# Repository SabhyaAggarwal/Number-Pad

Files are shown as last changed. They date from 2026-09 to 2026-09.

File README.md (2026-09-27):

# Number Pad
This is a keyboard made by me that acts as a number pad for many keyboards today that don't include it, and it's designed for use in, say, the calculator app. The PCB was designed in Ki-CAD, the case was designed in Onshape, and it uses QMK firmware. As per me, the  design and shape is beautiful...

## BOM
|Name |Description |Quantity|Total Cost|Link |Distributor |
|---|---|---|---|---|---|
|PCB |Main PCB(includes payment fee) |1 |$1.36 |https://aivon.com/ |AIVON |
|Seeed Studio XIAO RP2040|Main Dev Board(cost includes shipping) |1 |$8.72 |https://sharvielectronics.com/product/xiao-rp2040-supports-arduino-micropython-and-circuitpython-seeed-studio/|sharvi electronics|
|MX Switches |MX switches(pack of 10 and 2 of them = 20 keys)(includes shipping) |2 |$5.11 |https://stackskb.com/store/click-inc-hp-switch-pack-of-10-pre-order/ |stackskb |
|Keycaps |Numpad keycaps(shipping grouped with switches) |1 |$1.57 |https://stackskb.com/store/numpad-keycaps/?attribute_variant=MDA+Lavender |stackskb |
|1N4148 Diode |1N4148 Diode(price not include shipping as shipping is shared with the XIAO RP2040)|17 |$0.60 |https://sharvielectronics.com/product/1n4148-small-signal-fast-switching-diodes-do-35-package/ |sharvi electronics |
|2u MX Stabilizers |Stabilizers(shipping grouped with switches) |3 |$3.13 |https://stackskb.com/store/genuine-cherry-mx-plate-mount-stabilizers-2u/ |stackskb |

## Images

### CAD
#### 3D Renders of the Number Pad

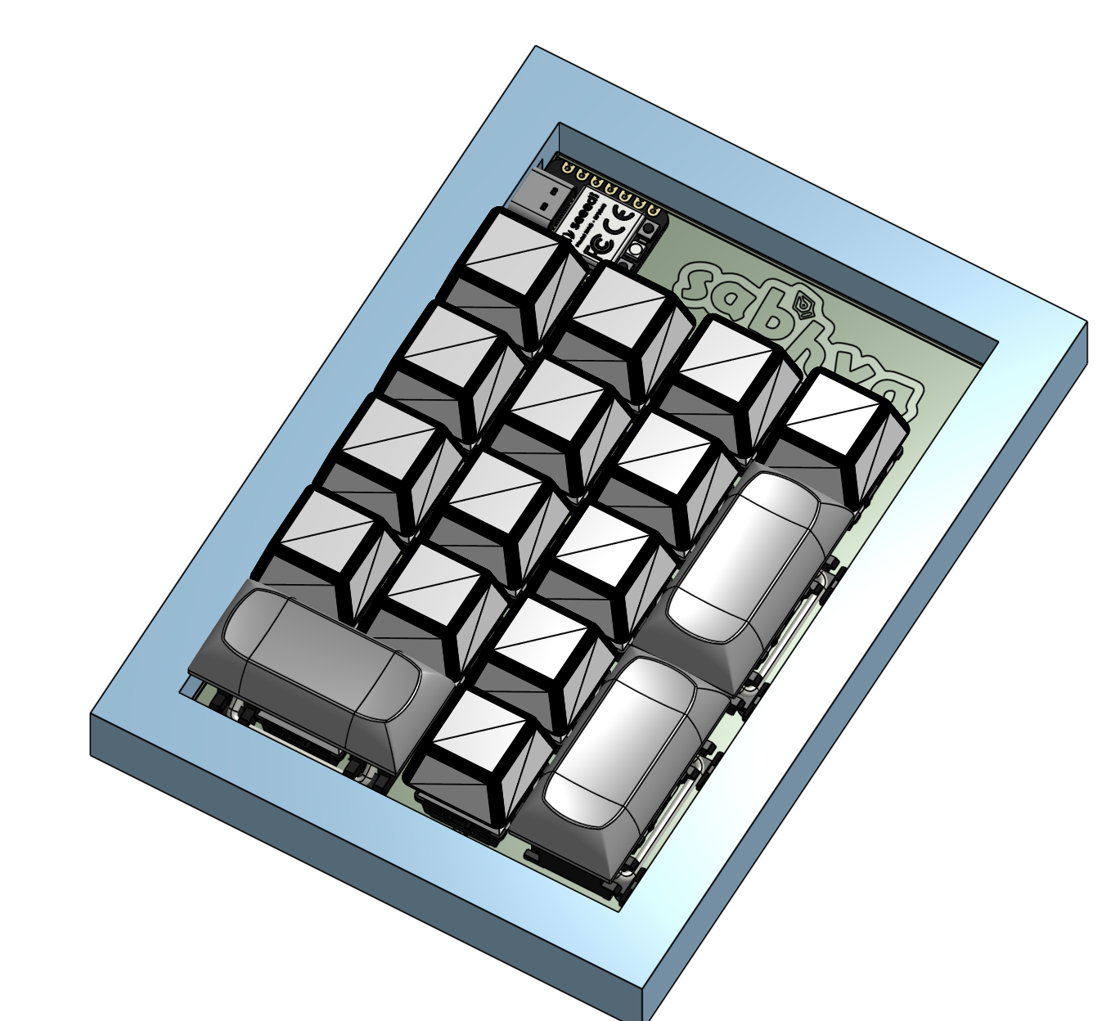
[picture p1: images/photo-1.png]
3D render 1


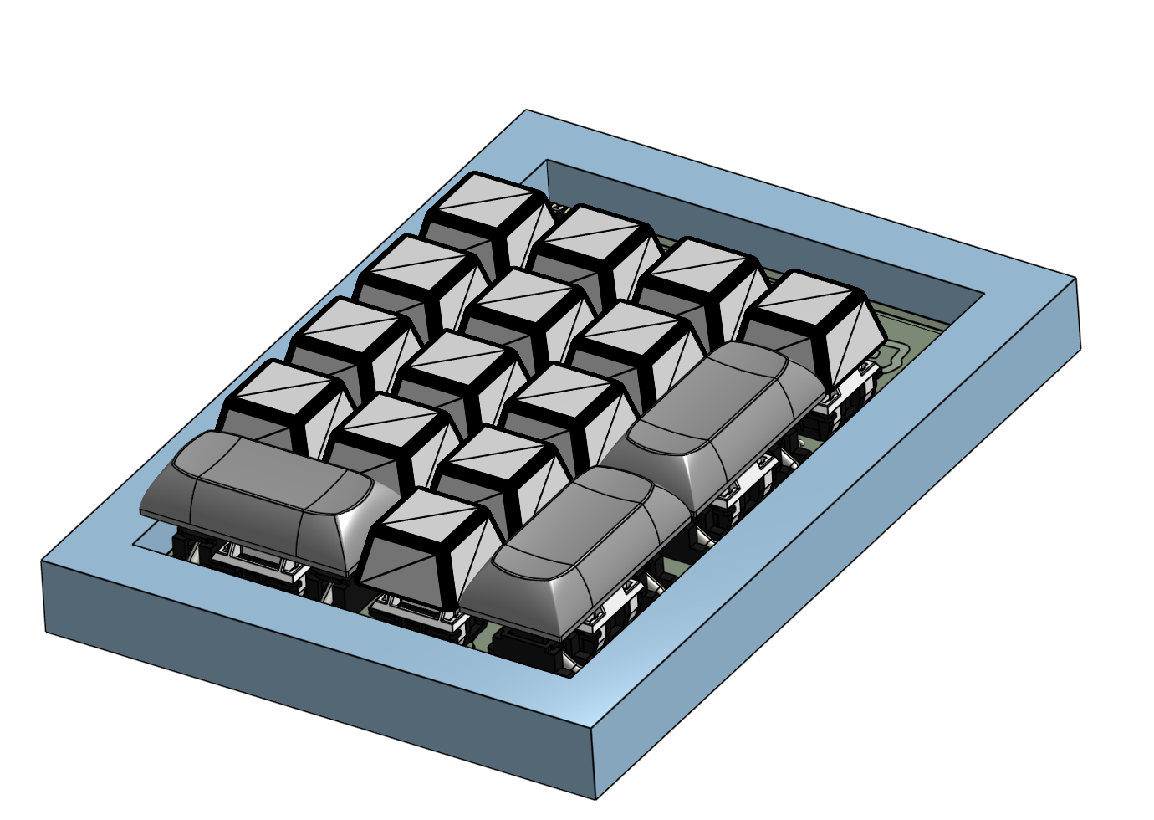
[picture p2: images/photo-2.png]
3D render 2


#### 3D render of Case

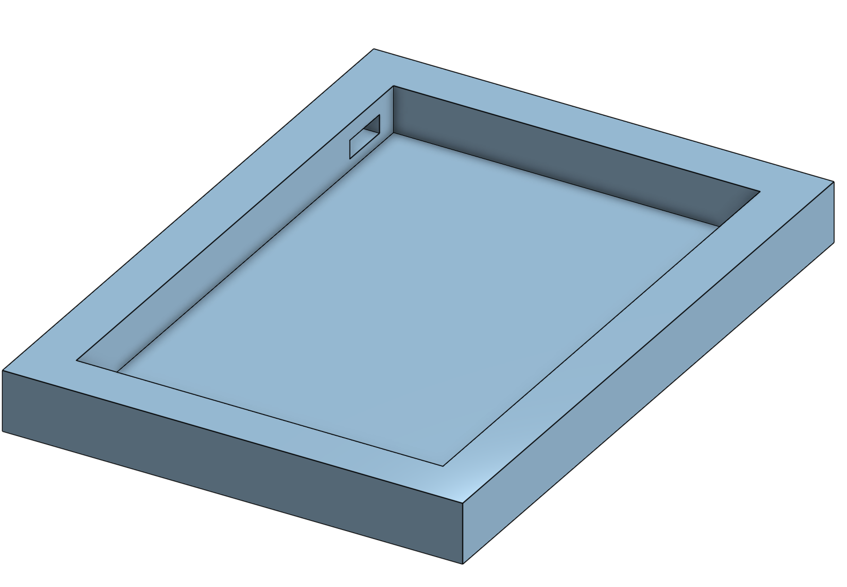
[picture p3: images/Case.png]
case


#### 3D render of Plate

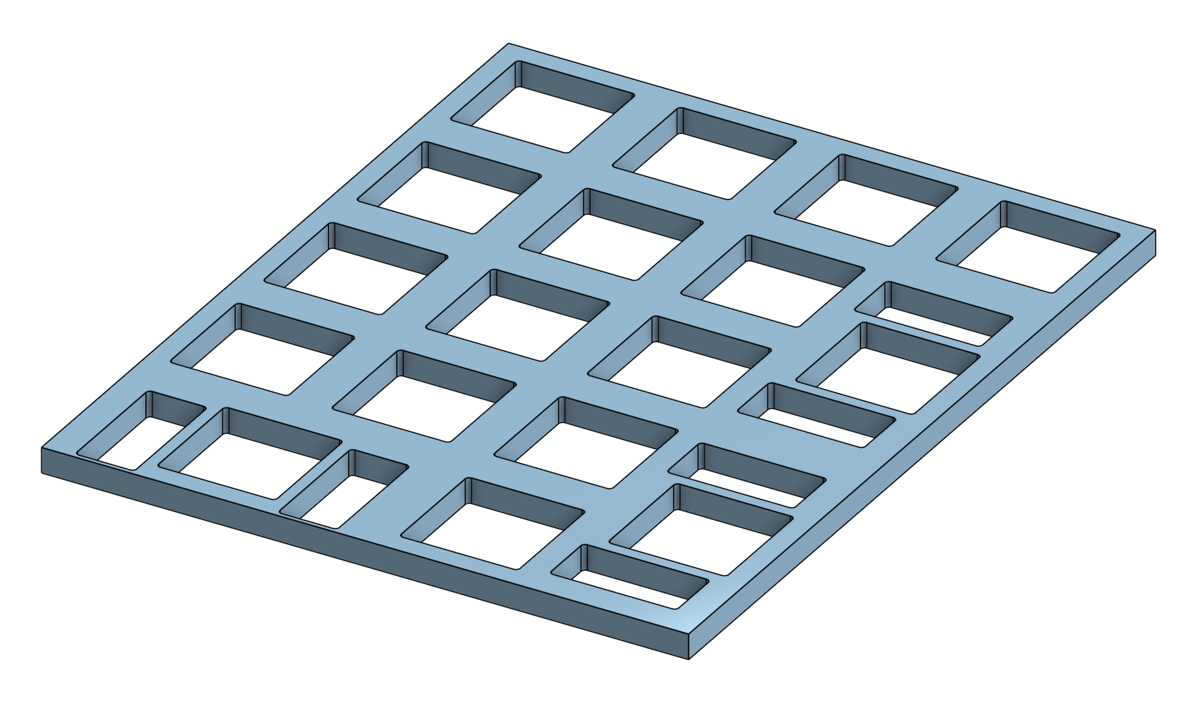
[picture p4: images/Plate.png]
plate


###### Note: Earlier I decided I would have an OLED. Later I decided I should not. [This](https://cad.onshape.com/documents/dad228ea60076f74a46a1f61/w/2f4558e967e48aff5bcd16fe/e/fbd68186b11d7caaa4edcef6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) link is for the one which shows the OLED would be there but actually we're not going to place it that way. I am just giving that link because it has the exact correct placements and it also has the plate and case Part Studio, and for the one with none. of them, it's [this](https://cad.onshape.com/documents/9043f20461557082fc912c61/w/6b8636902849ed63c82f6d7b/e/4d242b45682191a3636d33f8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)...
### PCB

#### 3D render of PCB

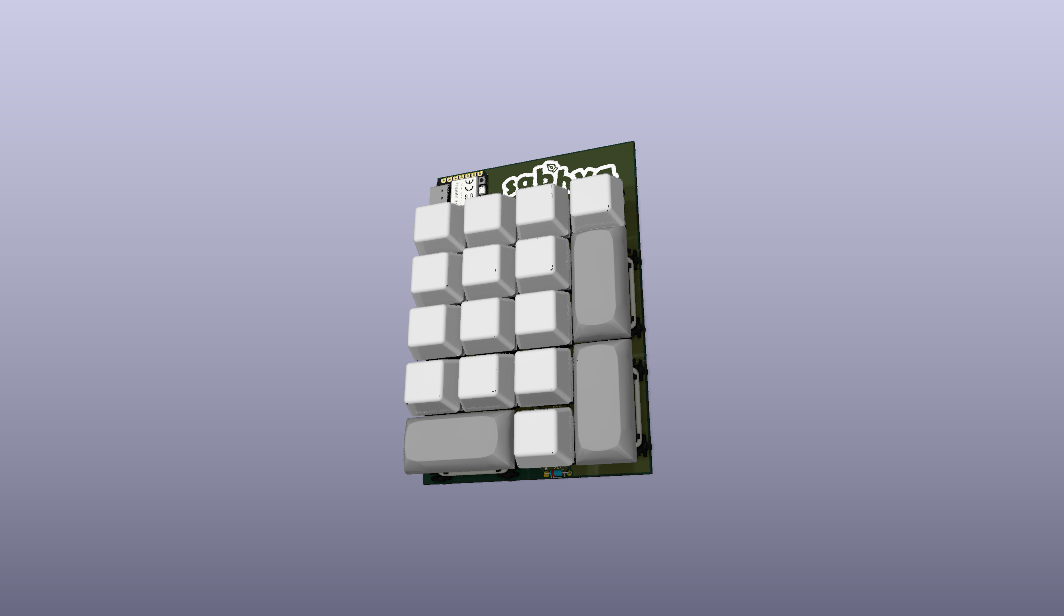
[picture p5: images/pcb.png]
pcb


#### PCB layout 

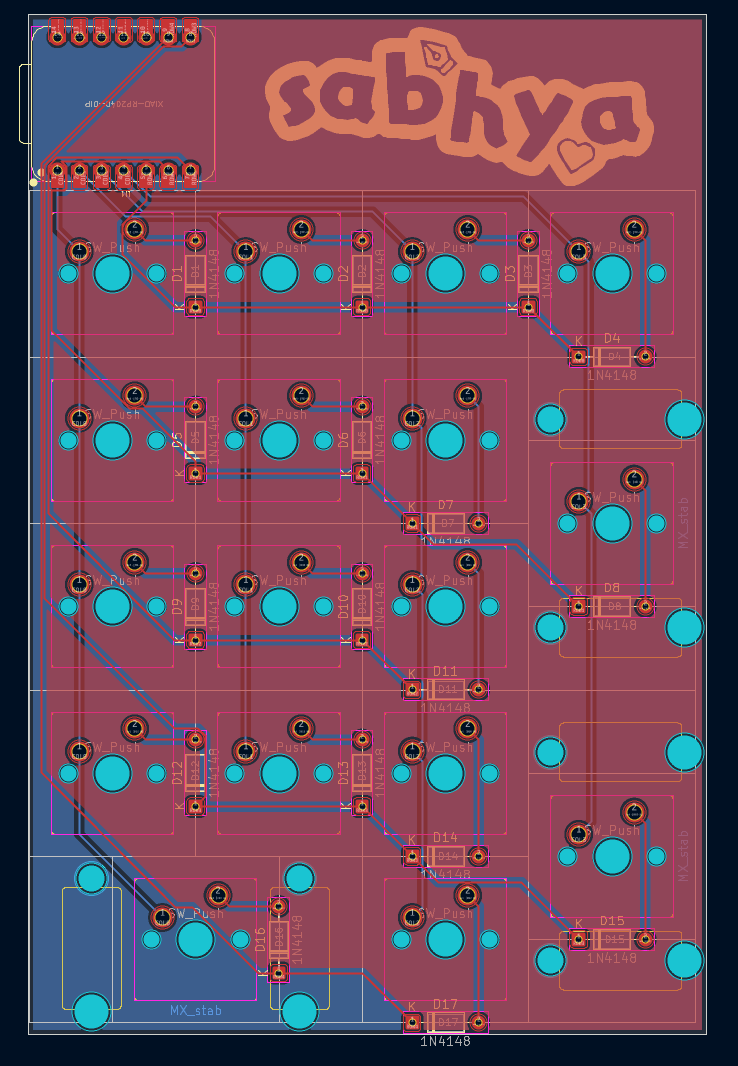
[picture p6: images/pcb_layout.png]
pcb layout


#### Schematic

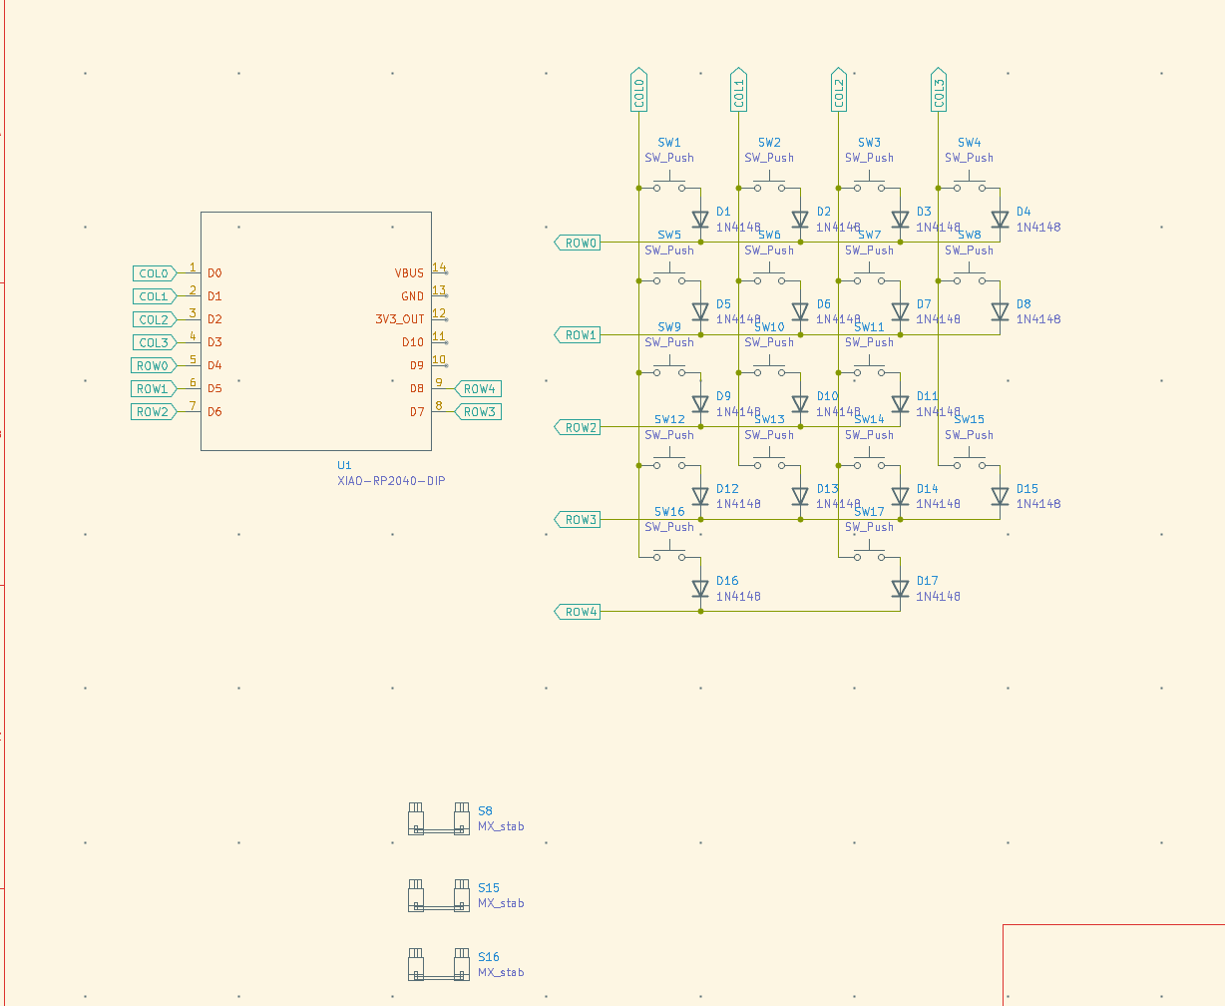
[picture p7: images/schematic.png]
schematic


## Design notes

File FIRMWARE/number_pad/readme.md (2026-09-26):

# number_pad

A 5x4 numpad built around an RP2040 (Pro Micro / Pico style footprint).

* Keyboard Maintainer: [Sabhya Aggarwal](https://github.com/SabhyaAggarwal)
* Hardware Supported: RP2040 (Pro Micro ATmega32U4 pin-compatible controller)
* Hardware Availability: https://github.com/SabhyaAggarwal/Number-Pad

Make example for this keyboard (after setting up your build environment):

    qmk compile -kb number_pad -km default

Flashing example for this keyboard:

    qmk flash -kb number_pad -km default

See [build environment setup](https://docs.qmk.fm/#/getting_started_build_tools) then the [make instructions](https://docs.qmk.fm/#/getting_started_make_guide) for more information.

## Bootloader

Enter the bootloader in 3 ways:

* **Bootmagic reset**: Hold down the key at (0,0) in the matrix (top left key, `Num`) and plug in the keyboard
* **Physical reset button**: Briefly press the reset button on the back of the PCB
* **Keycode in layout**: Press the key mapped to `QK_BOOT` if it is available

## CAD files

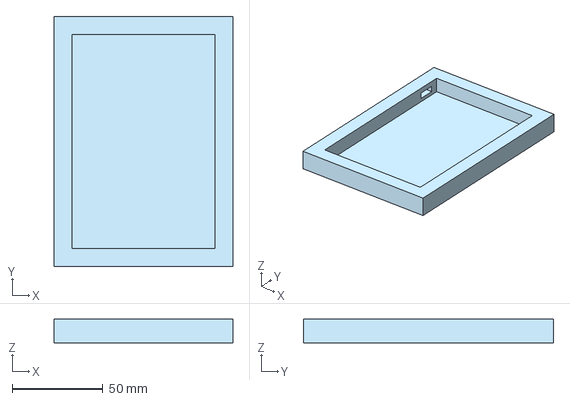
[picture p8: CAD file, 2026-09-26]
CAD/Case.step
98.4 x 137.5 x 13.0 mm

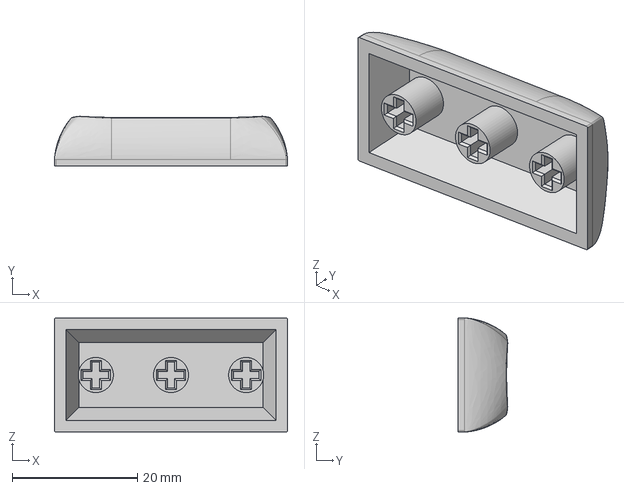
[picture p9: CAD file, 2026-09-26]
PCB/DSA 2u.step
37.2 x 7.91 x 18.2 mm

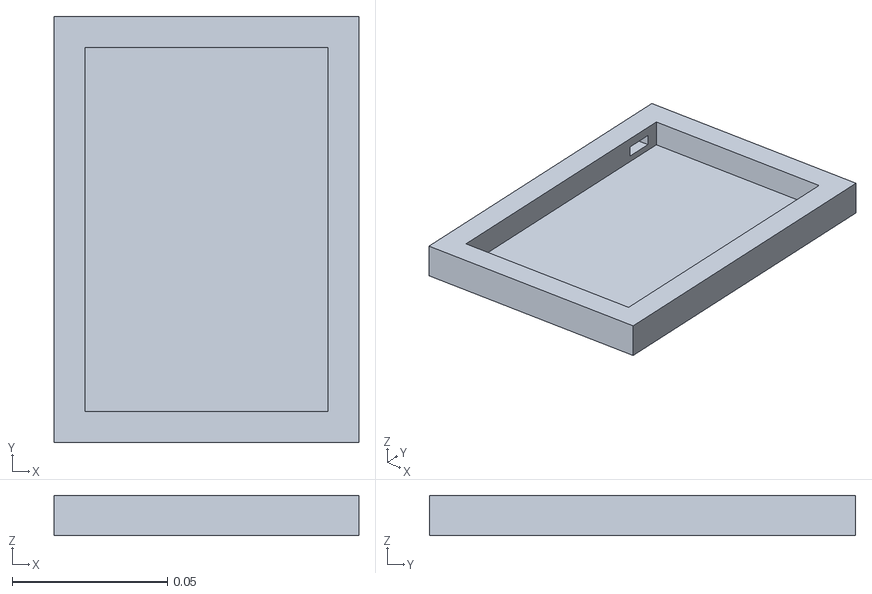
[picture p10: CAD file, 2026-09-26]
PRODUCTION/Case.stl
0.0984 x 0.137 x 0.013

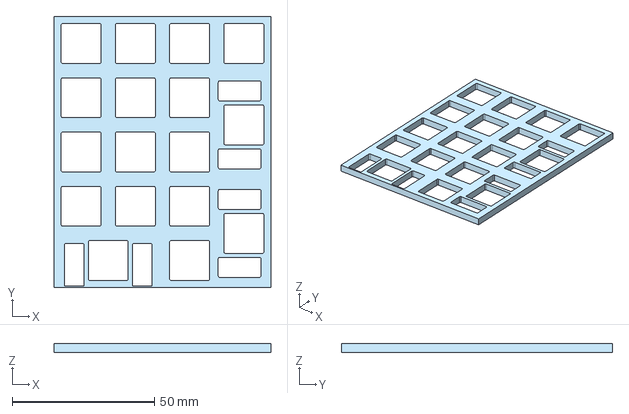
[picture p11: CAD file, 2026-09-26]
CAD/Plate.step
76.2 x 95.2 x 3.00 mm

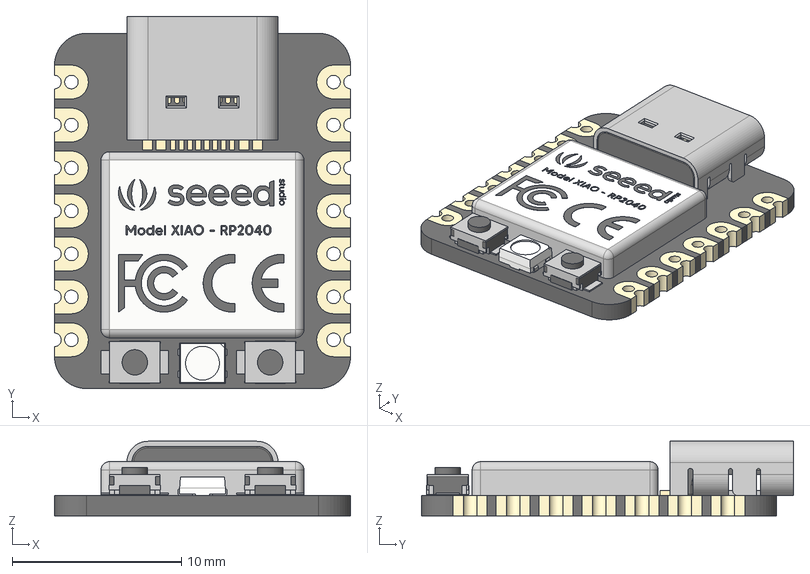
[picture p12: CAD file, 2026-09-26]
PCB/Seeed Studio XIAO RP2040 v26.step
17.5 x 22.0 x 4.40 mm
type-c v2
smd_button v3
DOUT
DIN
VSS
VDD
smd_button v3(Mirror)

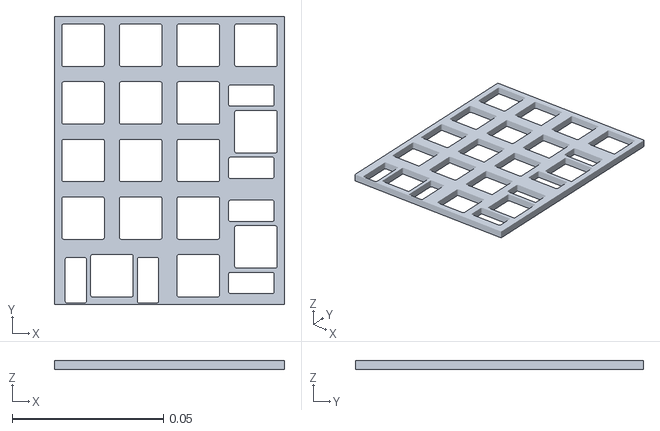
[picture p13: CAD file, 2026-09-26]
PRODUCTION/Plate.stl
0.0762 x 0.0953 x 0.003

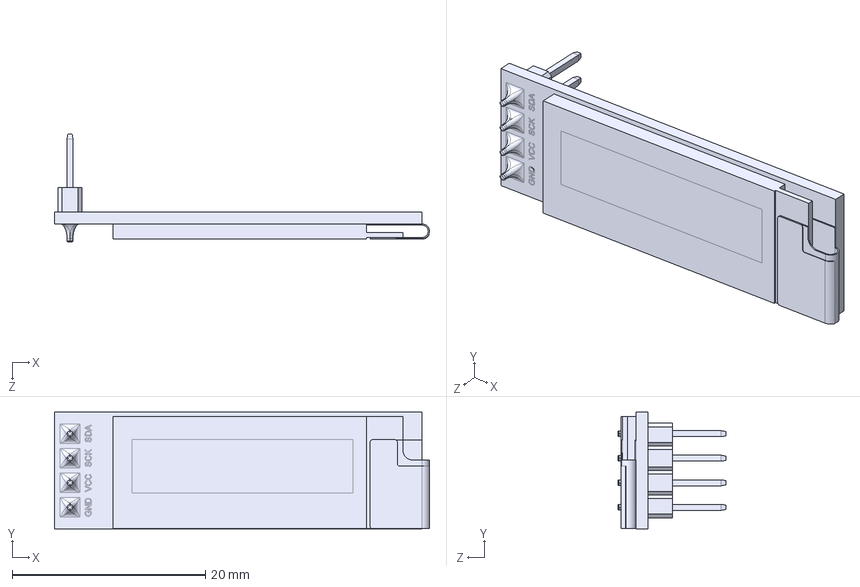
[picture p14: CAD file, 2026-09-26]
PCB/0.91in OLED.STEP
38.8 x 12.1 x 11.2 mm

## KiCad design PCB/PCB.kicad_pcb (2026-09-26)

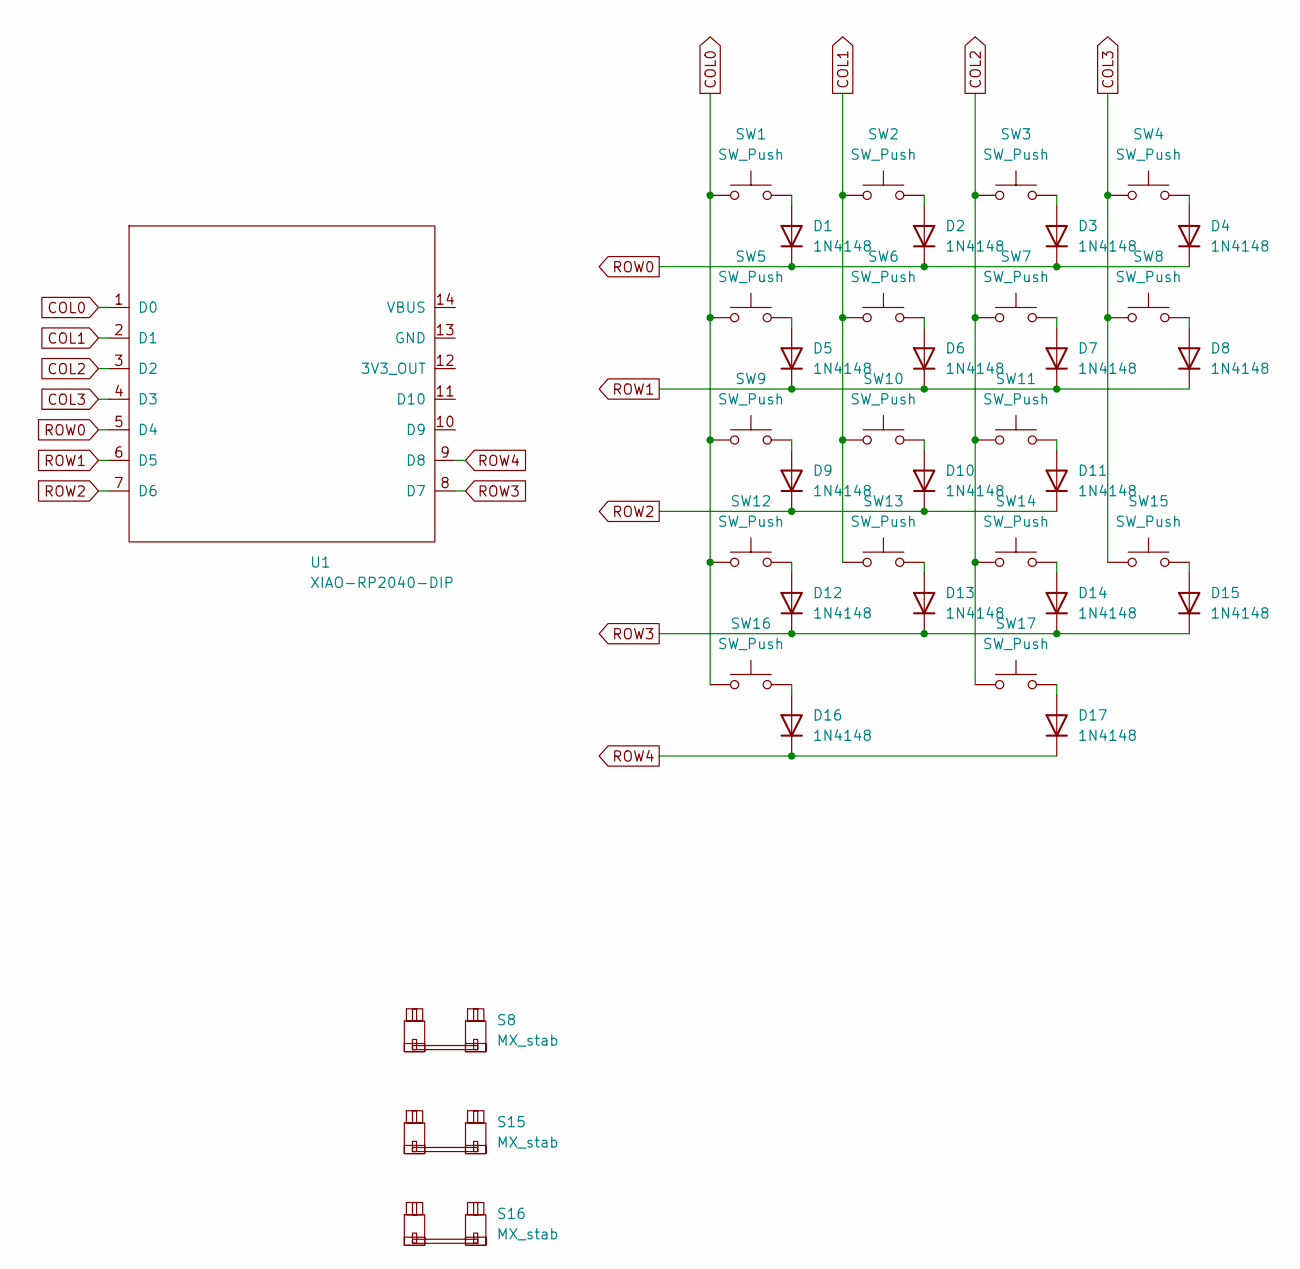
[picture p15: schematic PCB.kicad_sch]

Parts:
D1, D2, D3, D4, D5, D6, D7, D8, D9, D10, D11, D12, D13, D14, D15, D16, D17: 1N4148; D_DO-35_SOD27_P7.62mm_Horizontal
S8, S15, S16: MX_stab; STAB_MX_2u
SW1, SW2, SW3, SW4, SW5, SW6, SW7, SW8, SW9, SW10, SW11, SW12, SW13, SW14, SW15, SW16, SW17: SW_Push; SW_MX_1u
U1: XIAO-RP2040-DIP

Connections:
COL0: SW1.1, SW5.1, SW9.1, SW12.1, SW16.1, U1.1 (D0)
COL1: SW2.1, SW6.1, SW10.1, SW13.1, U1.2 (D1)
COL2: SW3.1, SW7.1, SW11.1, SW14.1, SW17.1, U1.3 (D2)
COL3: SW4.1, SW8.1, SW15.1, U1.4 (D3)
unnamed: D1.2 (A), SW1.2
unnamed: D2.2 (A), SW2.2
unnamed: D3.2 (A), SW3.2
unnamed: D4.2 (A), SW4.2
unnamed: D5.2 (A), SW5.2
unnamed: D6.2 (A), SW6.2
unnamed: D7.2 (A), SW7.2
unnamed: D8.2 (A), SW8.2
unnamed: D9.2 (A), SW9.2
unnamed: D10.2 (A), SW10.2
unnamed: D11.2 (A), SW11.2
unnamed: D12.2 (A), SW12.2
unnamed: D13.2 (A), SW13.2
unnamed: D14.2 (A), SW14.2
unnamed: D15.2 (A), SW15.2
unnamed: D16.2 (A), SW16.2
unnamed: D17.2 (A), SW17.2
ROW0: D1.1 (K), D2.1 (K), D3.1 (K), D4.1 (K), U1.5 (D4)
ROW1: D5.1 (K), D6.1 (K), D7.1 (K), D8.1 (K), U1.6 (D5)
ROW2: D9.1 (K), D10.1 (K), D11.1 (K), U1.7 (D6)
ROW3: D12.1 (K), D13.1 (K), D14.1 (K), D15.1 (K), U1.8 (D7)
ROW4: D16.1 (K), D17.1 (K), U1.9 (D8)

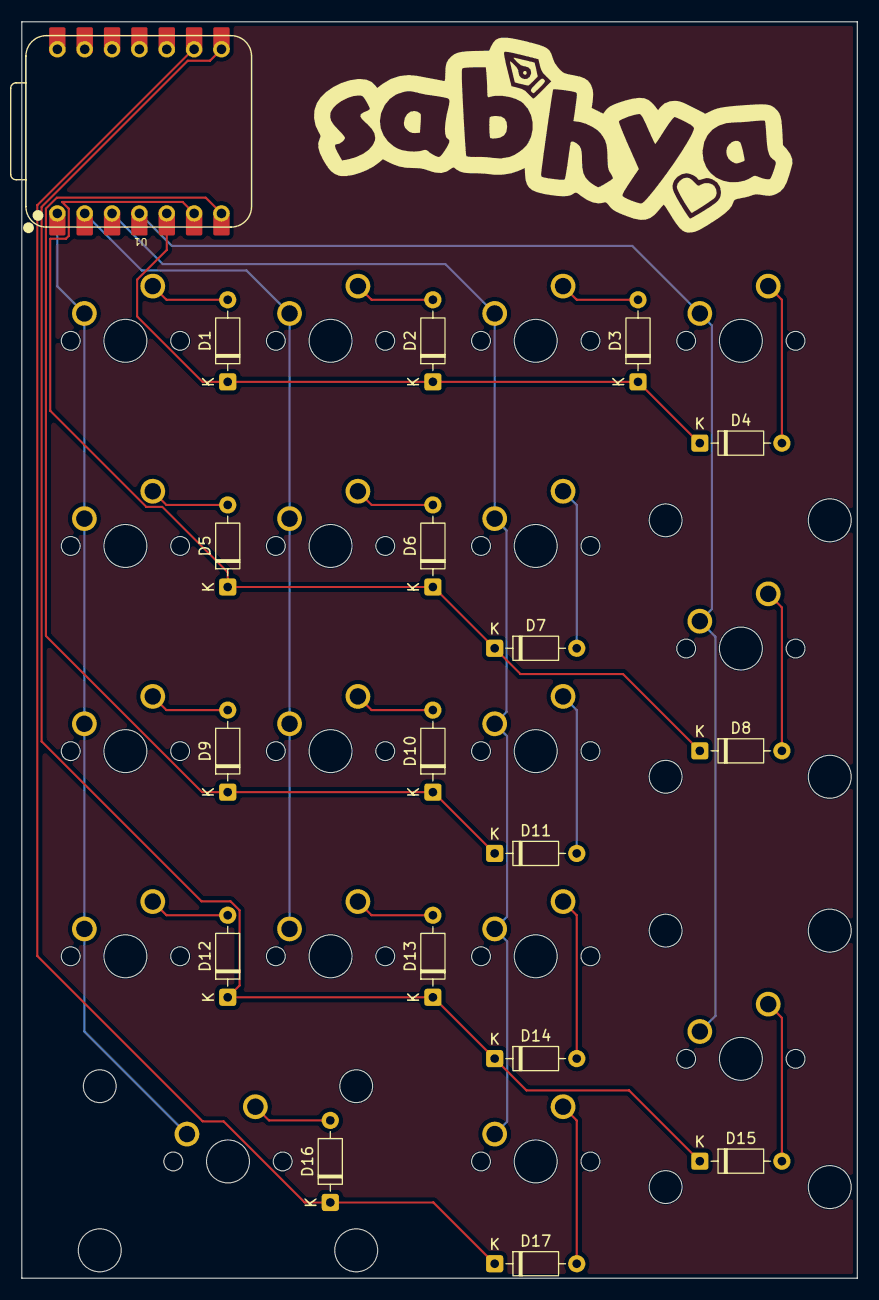
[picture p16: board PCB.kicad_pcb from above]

Board: 2 copper layers, 77.6 x 116.7 mm, 38 parts (0 on the bottom side), 26 nets.

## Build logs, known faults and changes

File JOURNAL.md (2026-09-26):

---
title: "Number Pad"
author: "Sabhya Aggarwal"
description: "It's a num pad that can come on the side of your laptop and can plug right in..."
created_at: "2026-09-26"
---

# September 25: Designed the schematic

I fount the layout I wanted and I shipped up the schematic... no issues encountered, just smooth sailing

schematic

https://lapse.hackclub.com/timelapse/_0DMw2MbVH4r

**Total time spent: 0.5072463768 hours**

# September 26: Made the entire PCB and did routing

I basically just placed all the switches and stabilizers in the right place and routed it. I faced little to no problems. It was quite smooth...

pcb layout

pcb 3d render

https://lapse.hackclub.com/timelapse/Wk0bybHFVrAW

**Total time spent: 1.5 hours**

# September 26:  made the case, made the bom, made the README, finished the project. Thank God

I made the entire project, the entire case, and finished it. Thank God. The only problem was when I realized I should not put in the OLED because it's too much extra effort. Otherwise it was nice.  I also somehow missed recording like 45 minutes of work...





**Total time spent: 2.5 hours**

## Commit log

2026-09-26 A commit I think
    [0.91in OLED.STEP, DSA 2u.step, PCB.kicad_pcb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]
2026-09-26 why was this not in previous commit?
    [Case.step, Case.stl, PCB.kicad_pcb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]
